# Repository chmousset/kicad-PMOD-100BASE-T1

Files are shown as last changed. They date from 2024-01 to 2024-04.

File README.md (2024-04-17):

# PMOD-LAN8720
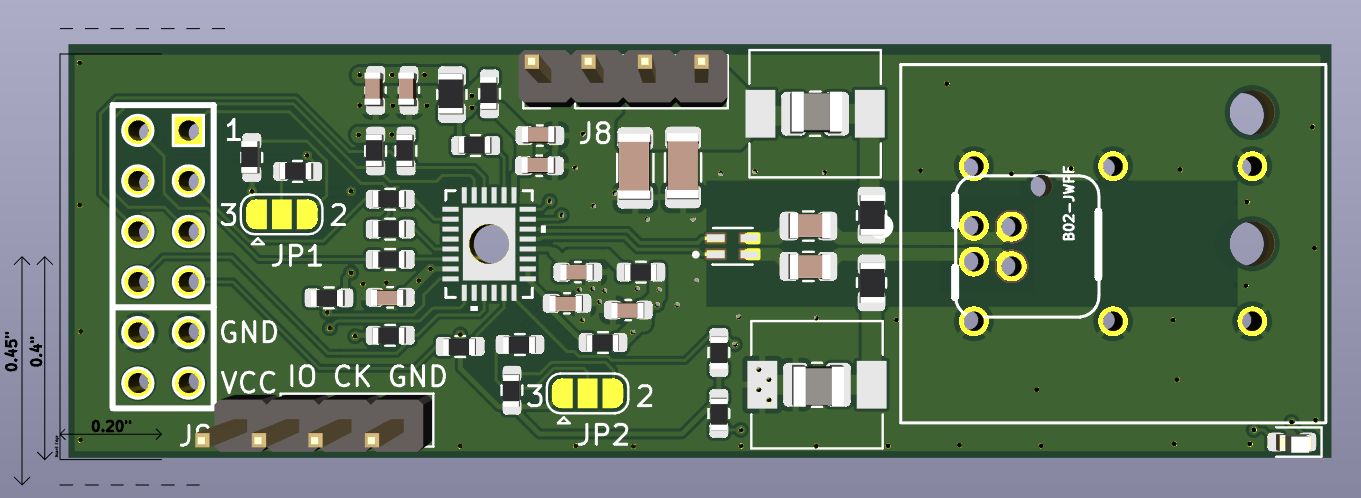
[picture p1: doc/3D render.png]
3D render 3D rendering

This is a single-width PMOD module with the RMII DP83TC813 100BASE-T1 PHY.

## Master/Slave
**100BASE-T1 require one of the device to be setup as a Slave, and the other one as a Master.** This concept doesn't exist in 100BASE-T and most usual Ethernet types, and seems to be a particularity of 100BASE-T1 and 1000BASE-T1. Check R42 placement to setup Master/Slave mode.

## Configuration
Straps have been setup for RMII slave mode (refclk has to be supplied from the host at 50MHz), 100BASE-T1 Master Mode (R43 present) and MDIO PHYADD=0 (JP1 and JP2 open).

### Master/Slave
When R42 is placed, the DP83TC813 acts as a **Master**. When R42 isn't placed, the internal pulldown of the PHY enables the **Slave** mode.

### Phyaddress
MDIO PHY address is set with JP1 and JP2. 9 different addresses can be configured:

| JP1  | JP2  | PHYADD[0-1] | PHYADD[2-3] | PHYADD |
|---|---|---|---|---|
| OPEN | OPEN | 0b00 | 0b00 | 0b0000 |
| 1-2  | OPEN | 0b11 | 0b00 | 0b0011 |
| 2-3  | OPEN | 0b01 | 0b00 | 0b0001 |
| OPEN | 1-2  | 0b00 | 0b11 | 0b1100 |
| 1-2  | 1-2  | 0b11 | 0b11 | 0b1111 |
| 2-3  | 1-2  | 0b01 | 0b11 | 0b1101 |
| OPEN | 2-3  | 0b00 | 0b01 | 0b0100 |
| 1-2  | 2-3  | 0b11 | 0b01 | 0b0111 |
| 2-3  | 2-3  | 0b01 | 0b01 | 0b0101 |

## Pinout
| Pin | type  | Function | Description |
|-----|---|---|---|
| 1 | I | TX_D1 | Transmit Data |
| 2 | I | TXEN | Transmit Enable |
| 3 | O | RX_D0 | Receive Data |
| 4 | I | REFCLK | 50MHz clock |
| 5 | | GND | |
| 6 | | VCC | 3.3V rail |
| 7 | I | TX_D0 | Transmit Data |
| 8 | O | RX_DV | Receive / Data valid |
| 9 | O | RX_D1 | Receive Data |
| 10  | I, PU | RST_T1 | Reset |
| 11  | | GND | |
| 12  | | VCC | 3.3V rail |

Legend:
- I: input (ie. output from the host)
- O: output (ie. input from the host)
- PU: Pull-up

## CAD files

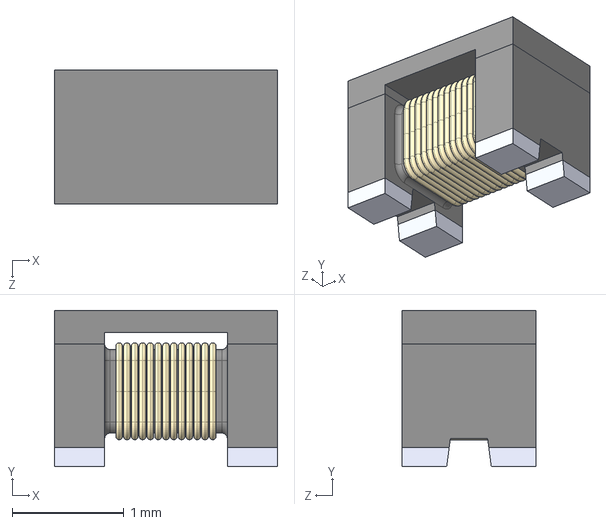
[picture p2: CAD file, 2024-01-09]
DLW21SZ181XQ2L/DLW21SZ181XQ2L.step
2.00 x 1.40 x 1.20 mm

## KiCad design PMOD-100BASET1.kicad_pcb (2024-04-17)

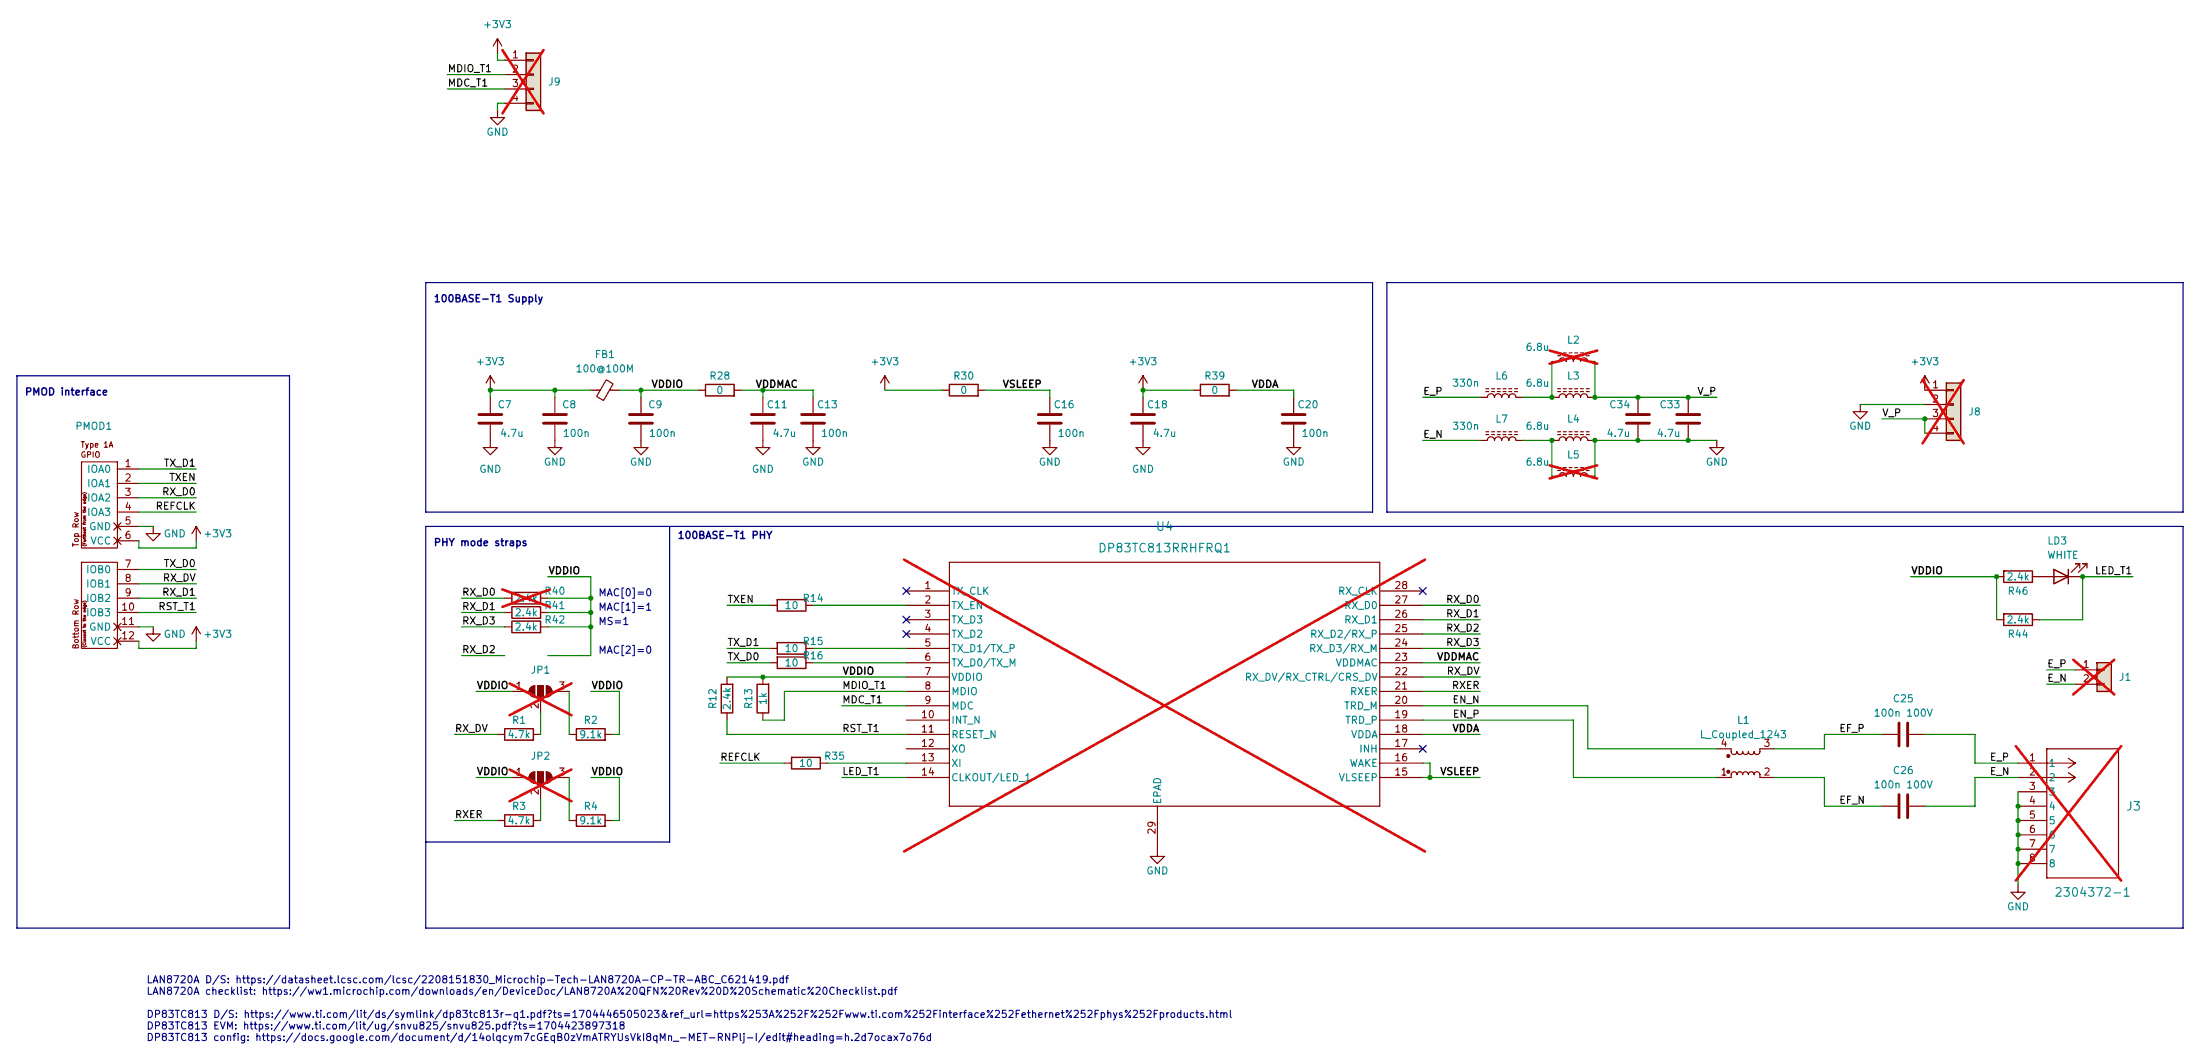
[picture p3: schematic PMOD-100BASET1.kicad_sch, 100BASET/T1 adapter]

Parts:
C7, C11, C18: 4.7u; C_0603_1608Metric; LCSC C19666
C8, C9, C13, C16, C20: 100n; C_0603_1608Metric; LCSC C14663
C25, C26: 100n 100V; C_0805_2012Metric; LCSC C28233
C33, C34: 4.7u; C_1206_3216Metric; LCSC C29823
FB1: 100@100M; R_0805_2012Metric; LCSC C1015
J1: Conn_01x02; B02B-JWPF-SK-R; LCSC C5305323; not fitted
J3: 2304372-1; CONN2_9-2304372_TEC; not fitted
J8, J9: Conn_01x03; PinHeader_1x04_P2.54mm_Vertical; not fitted
JP1, JP2: SolderJumper_3_Open; SolderJumper-3_P1.3mm_Open_RoundedPad1.0x1.5mm; not fitted
L1: L_Coupled_1243; FIL_DLW21SZ181XQ2L; LCSC C76896
L2, L5: 6.8u; L_6.3x6.3_H3; not fitted
L3, L4: 6.8u; L_1008_2520Metric; LCSC C2041474
L6, L7: 330n; R_0805_2012Metric; LCSC C92051
LD3: WHITE; LED_0603_1608Metric; LCSC C2290
PMOD1: PMOD-Device-x2-Type-1A-GPIO; pmod_pin_array_6x2; LCSC C492434
R1, R3: 4.7k; R_0603_1608Metric; LCSC C23162
R2, R4: 9.1k; R_0603_1608Metric; LCSC C23260
R12, R41, R42, R44, R46: 2.4k; R_0603_1608Metric; LCSC C22940
R13: 1k; R_0603_1608Metric; LCSC C21190
R14, R15, R16, R35: 10; R_0603_1608Metric; LCSC C22859
R28, R30, R39: 0; R_0603_1608Metric; LCSC C21189
R40: 2.4k; R_0603_1608Metric; LCSC C22940; not fitted
U4: DP83TC813RRHFRQ1; VQFN28_RHF_TEX; not fitted

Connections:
+3V3: C7.2, C8.2, C18.2, FB1.1, J8.1, J9.1, PMOD1.6 (VCC), PMOD1.12 (VCC), R30.1, R39.1
/EF_N: C26.2, L1.2
/EF_P: C25.2, L1.3
/EN_N: L1.4, U4.20 (TRD_M)
/EN_P: L1.1, U4.19 (TRD_P)
/E_N: C26.1, J1.2, J3.2, L7.2
/E_P: C25.1, J1.1, J3.1, L6.2
/LED_T1: LD3.1 (K), R44.1, U4.14 (CLKOUT/LED_1)
/MDC_T1: J9.3, U4.9 (MDC)
/MDIO_T1: J9.2, R13.1, U4.8 (MDIO)
/REFCLK: PMOD1.4 (IOA3), R35.2
/RST_T1: PMOD1.10 (IOB3), R12.1, U4.11 (RESET_N)
/RXER: R3.1, U4.21 (RXER)
/RX_D0: PMOD1.3 (IOA2), R40.1, U4.27 (RX_D0)
/RX_D1: PMOD1.9 (IOB2), R41.1, U4.26 (RX_D1)
/RX_D2: U4.25 (RX_D2/RX_P)
/RX_D3: R42.1, U4.24 (RX_D3/RX_M)
/RX_DV: PMOD1.8 (IOB1), R1.1, U4.22 (RX_DV/RX_CTRL/CRS_DV)
/TXEN: PMOD1.2 (IOA1), R14.2
/TX_D0: PMOD1.7 (IOB0), R16.2
/TX_D1: PMOD1.1 (IOA0), R15.2
/VDDA: C20.2, R39.2, U4.18 (VDDA)
/VDDIO: C9.2, FB1.2, JP1.1 (A), JP2.1 (A), R2.2, R4.2, R12.2, R13.2, R28.1, R40.2, R41.2, R42.2, R44.2, R46.2, U4.7 (VDDIO)
/VDDMAC: C11.2, C13.2, R28.2, U4.23 (VDDMAC)
/VSLEEP: C16.2, R30.2, U4.15 (VLSEEP), U4.16 (WAKE)
/V_P: C33.1, C34.1, J8.3, J8.4, L2.1, L3.1
GND: C7.1, C8.1, C9.1, C11.1, C13.1, C16.1, C18.1, C20.1, C33.2, C34.2, J3.3, J3.4, J3.5, J3.6, J3.7, J3.8, J8.2, J9.4, L4.1, L5.1, PMOD1.5 (GND), PMOD1.11 (GND), U4.29 (EPAD)
unnamed: JP1.3 (B), R2.1
unnamed: JP1.2 (C), R1.2
unnamed: JP2.3 (B), R4.1
unnamed: JP2.2 (C), R3.2
unnamed: L2.2, L3.2, L6.1
unnamed: L4.2, L5.2, L7.1
unnamed: LD3.2 (A), R46.1
unnamed: R16.1, U4.6 (TX_D0/TX_M)
unnamed: R15.1, U4.5 (TX_D1/TX_P)
unnamed: R14.1, U4.2 (TX_EN)
unnamed: R35.1, U4.13 (XI)

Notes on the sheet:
100BASE-T1 PHY
MAC[0]=0
100BASE-T1 Supply
PHY mode straps
MS=1
LAN8720A D/S: https://datasheet.lcsc.com/lcsc/2208151830_Microchip-Tech-LAN8720A-CP-TR-ABC_C621419.pdf LAN8720A checklist: https://ww1.microchip.com/downloads/en/DeviceDoc/LAN8720A%20QFN%20Rev%20D%20Schematic%20Checklist.pdf DP83TC813 D/S: https://www.ti.com/lit/ds/symlink/dp83tc813r-q1.pdf?ts=1704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
MAC[1]=1
PMOD interface
MAC[2]=0

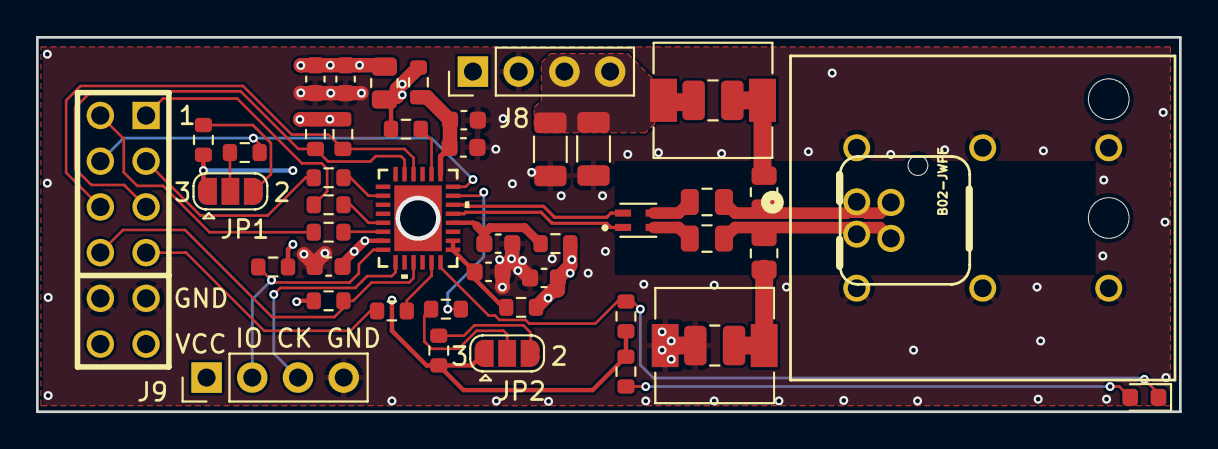
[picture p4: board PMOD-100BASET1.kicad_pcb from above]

Board: 4 copper layers, 63.5 x 20.8 mm, 47 parts (0 on the bottom side), 37 nets.

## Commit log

2024-01-09 [init] first production
    [DLW21SZ181XQ2L.step, PMOD-100BASET1.kicad_pcb, PMOD-100BASET1.kicad_sch]
2024-04-17 [doc] added readme; updated files to Kicad V8
    [PMOD-100BASET1.kicad_pcb, PMOD-100BASET1.kicad_sch]
